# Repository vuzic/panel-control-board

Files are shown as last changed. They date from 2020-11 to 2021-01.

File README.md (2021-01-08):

# Panel Control Hardware

## Power

### Requirements 
* Power button which either boots or sends a signal to the RPI to shutdown.
* Battery status indication (can be crude, maybe just color or flashing to indicate low battery vs charging vs charged)
* Should not draw too much current when off but fully charged
* OE needs to be disabled on panels when PI is off
* MCU with analog voltage from battery
* MCU needs to tell RPI to shut down when battery is <10%

### Ideas
* Use MOSFET rated for 15W (5V/3A) to power on the RPI
* RPI GPIO to act as a power status pin. Shutdown sequence waits for a level change on this pin before cutting the power.
    * High means PI is shutting down; when it goes low, its finished powering off.
# LED Interface

(old README, needs update)

This is a hat designed for a Raspberry Pi Zero. It consists of two headers for I2S microphones (the sort of which are availble for under 2$ on aliexpress) and two level shifted outputs.

The primary purpose is to control 4-wire LED strips using the four pin header. This should also be able to provide the Pi Zero with power.

There's also a HUB-75 connector for driving LED panels. This might be less useful, and probably wasn't neccessary. (These are much better suited to be driven off a PI 3 or 4 if the
frame rate or color depth matters, and some research into [hzeller's](https://github.com/hzeller/rpi-rgb-led-matrix) excellent library points out that the I2S CLK pin is also the same
as the PWM pin which drives the OE signal to the panels for better performance. I'm using a different pin mapping anyway (TODO: write it down..) so it wont work out of the box in any case.)

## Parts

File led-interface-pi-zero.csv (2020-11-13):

Comment | Designator | Footprint | LCSC
1uF | C1,C2,C3,C4 | Capacitor_SMD:C_0603_1608Metric_Pad1.08x0.95mm_HandSolder | C15849
3mm_Mounting_Hole | H1,H2,H3,H4 | project_footprints:NPTH_3mm_ID
PWR | J1 | Connector_PinHeader_2.54mm:PinHeader_2x02_P2.54mm_Vertical
103904-3 | J2 | user_footprints:TE_103904-3
40HAT | J3 | Connector_PinSocket_2.54mm:PinSocket_2x20_P2.54mm_Vertical
HUB-75 | J4 | user_footprints:TE_5-103167-5
ICS-43434 | MK1,MK2 | user_footprints:I2S-MIC_DIP-6
DMG2305UX | Q1 | Package_TO_SOT_SMD:SOT-23 | C150470
DMMT5401 | Q2 | Package_TO_SOT_SMD:SOT-23-6 | C154733
4.7K | R1 | Capacitor_SMD:C_0603_1608Metric_Pad1.08x0.95mm_HandSolder | C23162
100K | R3 | Resistor_SMD:R_0603_1608Metric_Pad0.98x0.95mm_HandSolder | C25803
47K | R5 | Resistor_SMD:R_0603_1608Metric_Pad0.84x1.00mm_HandSolder | C25819
10K | R6 | Resistor_SMD:R_0603_1608Metric_Pad0.84x1.00mm_HandSolder | C25804
TXS0108EPW | U1,U2 | Package_SO:TSSOP-20_4.4x6.5mm_P0.65mm | C17206

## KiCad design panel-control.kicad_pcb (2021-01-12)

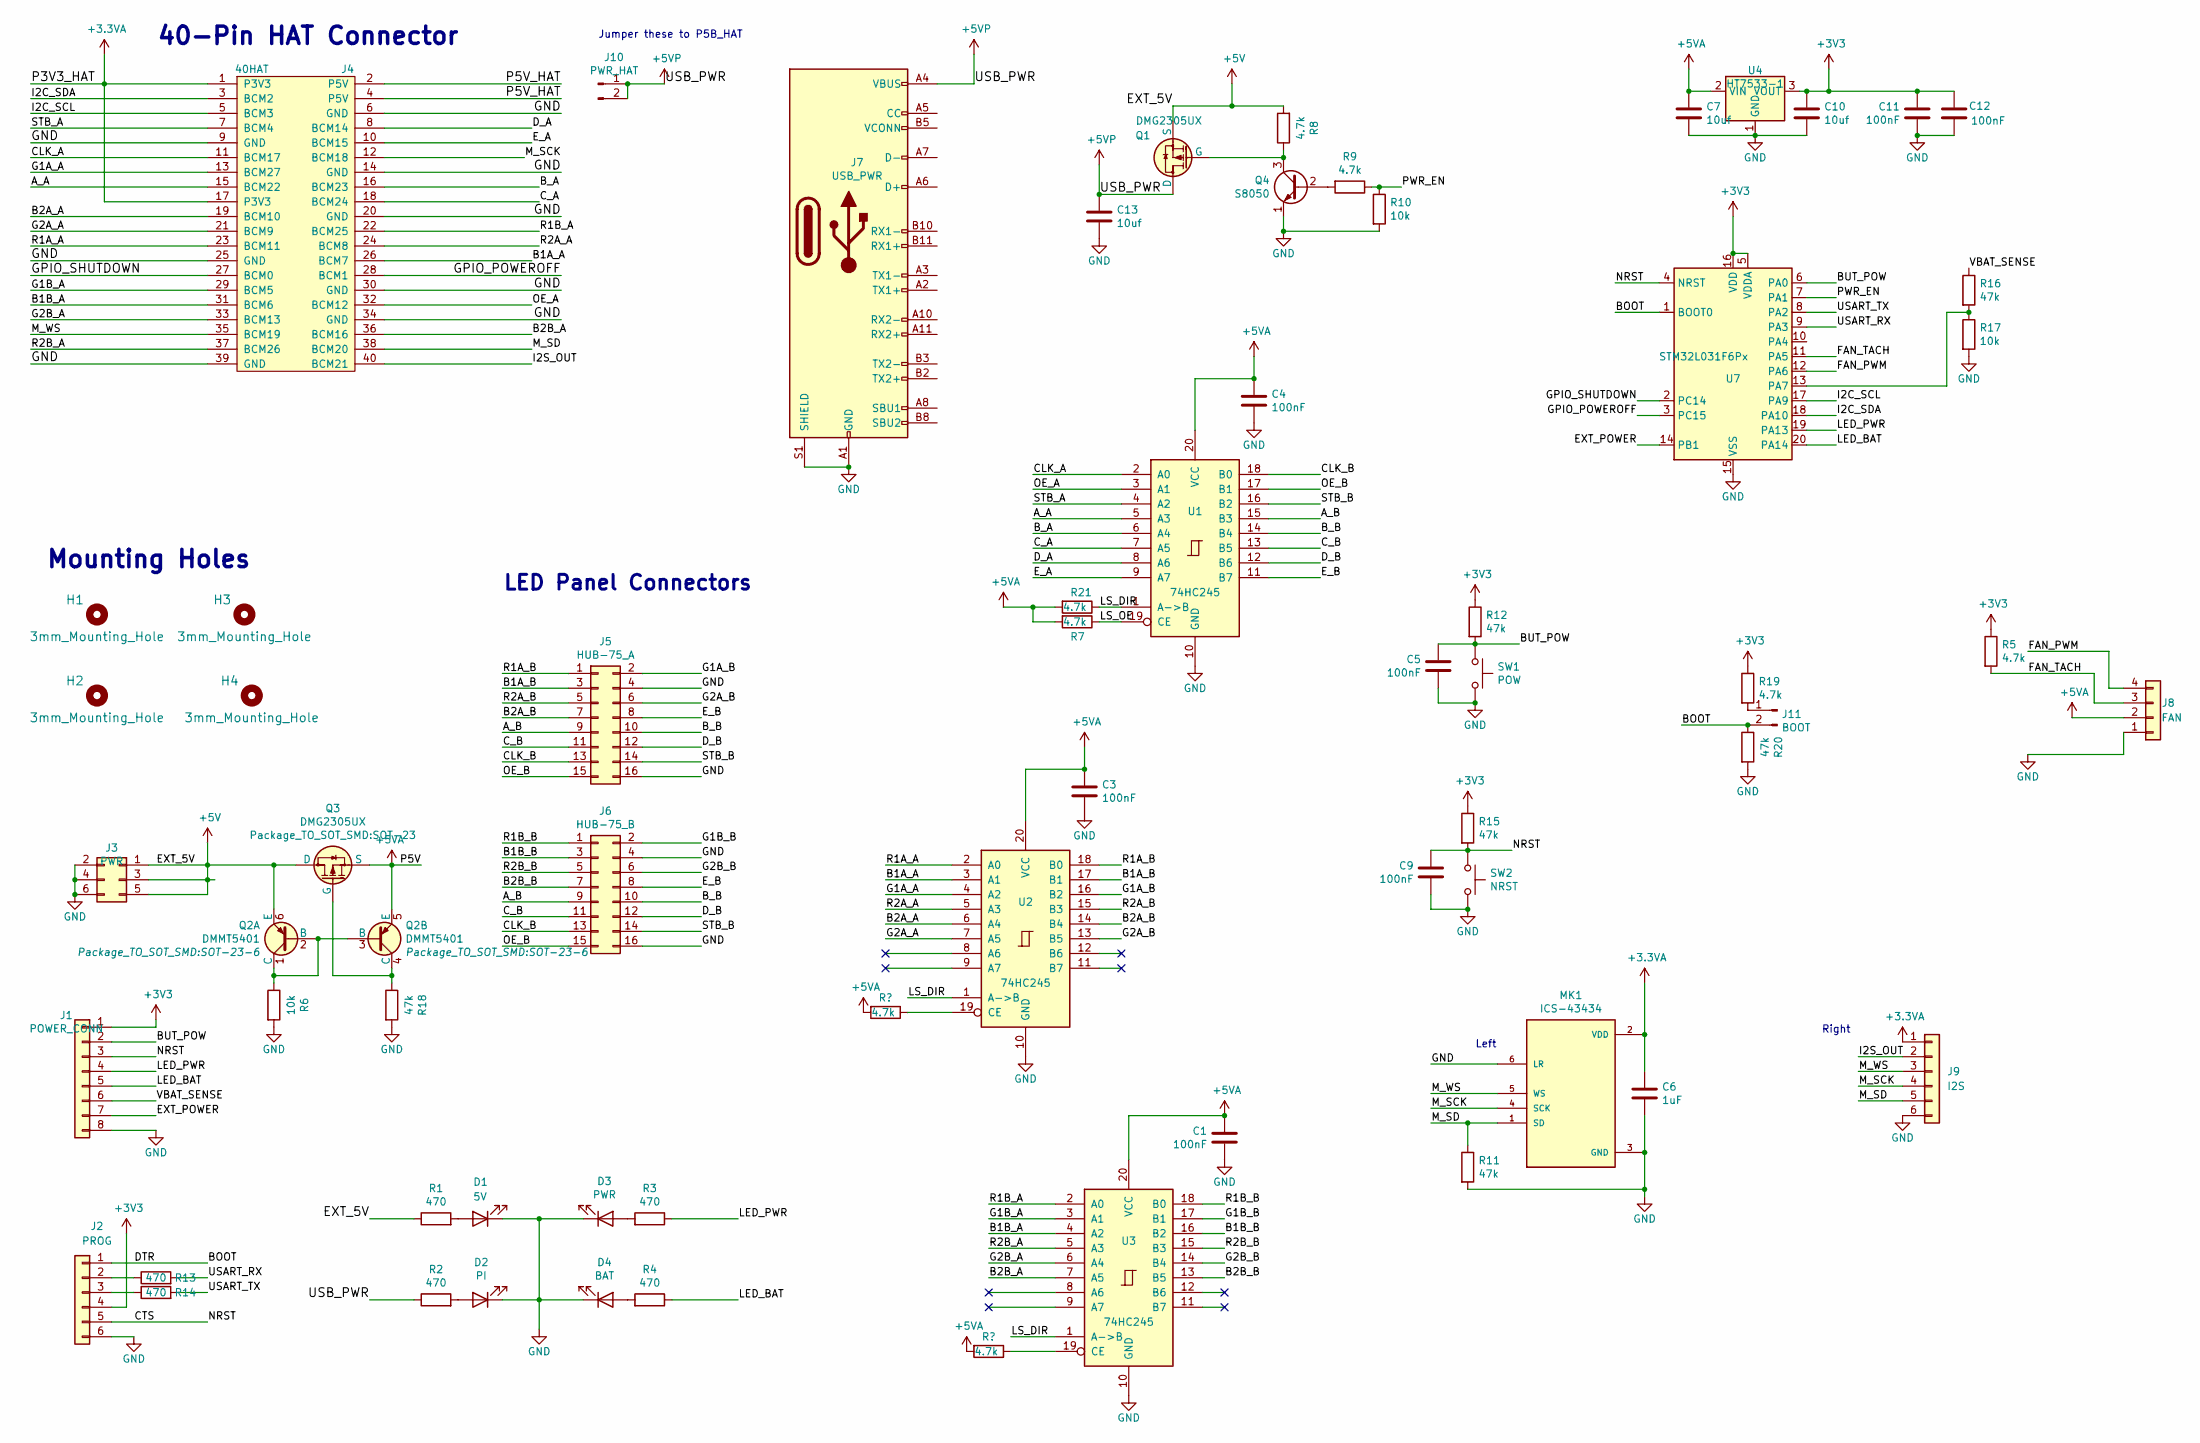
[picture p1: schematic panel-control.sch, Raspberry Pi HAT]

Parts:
C1, C3, C4, C5, C9, C11, C12: 100nF; C_0603_1608Metric; LCSC C14663
C6: 1uF; C_0603_1608Metric; LCSC C15849
C7, C10, C13: 10uf; C_0603_1608Metric; LCSC C19702
D1: 5V; LED_0603_1608Metric; LCSC C72038
D2: PI; LED_0603_1608Metric; LCSC C72038
D3: PWR; LED_0805_2012Metric; LCSC C2293
D4: BAT; LED_0805_2012Metric; LCSC C84256
H1, H2, H3, H4: 3mm_Mounting_Hole; NPTH_3mm_ID
J1: POWER_CONN; Molex_200528-0080_1x08-1MP_P1.00mm_Horizontal
J2: PROG; PinHeader_1x06_P2.54mm_Vertical
J3: PWR; PinHeader_2x03_P2.54mm_Vertical
J4: 40HAT; PinSocket_2x20_P2.54mm_Vertical
J5: HUB-75_A; IDC-Header_2x08_P2.54mm_Vertical
J6: HUB-75_B; IDC-Header_2x08_P2.54mm_Vertical
J7: USB_PWR; USB_C_Receptacle_GCT_USB4085
J8: FAN; FanPinHeader_1x04_P2.54mm_Vertical
J9: I2S; Molex_200528-0060_1x06-1MP_P1.00mm_Horizontal
J10: PWR_HAT; PinHeader_1x02_P2.54mm_Vertical
J11: BOOT; PinHeader_1x02_P2.54mm_Vertical
MK1: ICS-43434; I2S-MIC_DIP-6
Q1, Q3: DMG2305UX; SOT-23; LCSC C144153
Q2: DMMT5401; SOT-23-6; LCSC C154733
Q4: S8050; SOT-23; LCSC C2146
R1, R2, R3, R4, R13, R14: 470; R_0402_1005Metric; LCSC C25117
R5, R7, R8, R9, R19, R21: 4.7k; R_0402_1005Metric; LCSC C25900
R6: 10k; R_0402_1005Metric
R10, R17: 10k; R_0402_1005Metric; LCSC C25744
R11, R16: 47k; R_0402_1005Metric; LCSC C25792
R12, R15: 47k; R_0402_1005Metric; LCSC C25900
R18, R20: 47k; R_0402_1005Metric
SW1: POW; SW_Push_1P1T_NO_6x6mm_H9.5mm
SW2: NRST; SW_Push_1P1T_NO_6x6mm_H9.5mm
U1, U2, U3: 74HC245; SSOP-20_4.4x6.5mm_P0.65mm; LCSC C6779
U4: HT7533-1; SOT-89-3; LCSC C14289
U7: STM32L031F6Px; TSSOP-20_4.4x6.5mm_P0.65mm; LCSC C115208

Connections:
+3.3VA: C6.1, J4.1 (P3V3), J4.17 (P3V3), J9.1, MK1.2 (VDD)
+3V3: C10.1, C11.2, C12.2, J1.1, J2.4, R5.1, R12.1, R15.1, R19.1, U4.3 (VOUT), U7.5 (VDDA), U7.16 (VDD)
+5V: J3.1, J3.3, J3.5, Q1.2 (S), Q2.6 (E), Q3.3 (D), R1.1, R8.2
+5VA: C1.1, C3.1, C4.1, C7.1, J8.2, Q2.5 (E), Q3.2 (S), R7.2, R21.2, U1.20 (VCC), U2.20 (VCC), U3.20 (VCC), U4.2 (VIN); also elsewhere on the board
+5VP: C13.1, J7.A4 (VBUS), J7.A9 (VBUS), J7.B4 (VBUS), J7.B9 (VBUS), J10.1, J10.2, Q1.3 (D), R2.1
/A_A: J4.15 (BCM22), U1.5 (A3)
/A_B: J5.9, J6.9, U1.15 (B3)
/B1A_A: J4.26 (BCM7), U2.3 (A1)
/B1A_B: J5.3, U2.17 (B1)
/B1B_A: J4.31 (BCM6), U3.4 (A2)
/B1B_B: J6.3, U3.16 (B2)
/B2A_A: J4.19 (BCM10), U2.6 (A4)
/B2A_B: J5.7, U2.14 (B4)
/B2B_A: J4.36 (BCM16), U3.7 (A5)
/B2B_B: J6.7, U3.13 (B5)
/BOOT: J2.1, J11.2, R20.1, U7.1 (BOOT0)
/BUT_POW: C5.2, J1.2, R12.2, SW1.1, U7.6 (PA0)
/B_A: J4.16 (BCM23), U1.6 (A4)
/B_B: J5.10, J6.10, U1.14 (B4)
/CLK_A: J4.11 (BCM17), U1.2 (A0)
/CLK_B: J5.13, J6.13, U1.18 (B0)
/CTS: C9.2, J1.3, J2.5, R15.2, SW2.1, U7.4 (NRST)
/C_A: J4.18 (BCM24), U1.7 (A5)
/C_B: J5.11, J6.11, U1.13 (B5)
/D_A: J4.8 (BCM14), U1.8 (A6)
/D_B: J5.12, J6.12, U1.12 (B6)
/EXT_POWER: J1.7, U7.14 (PB1)
/E_A: J4.10 (BCM15), U1.9 (A7)
/E_B: J5.8, J6.8, U1.11 (B7)
/FAN_PWM: J8.4, U7.12 (PA6)
/FAN_TACH: J8.3, R5.2, U7.11 (PA5)
/G1A_A: J4.13 (BCM27), U2.4 (A2)
/G1A_B: J5.2, U2.16 (B2)
/G1B_A: J4.29 (BCM5), U3.3 (A1)
/G1B_B: J6.2, U3.17 (B1)
/G2A_A: J4.21 (BCM9), U2.7 (A5)
/G2A_B: J5.6, U2.13 (B5)
/G2B_A: J4.33 (BCM13), U3.6 (A4)
/G2B_B: J6.6, U3.14 (B4)
/GPIO_POWEROFF: J4.28 (BCM1), U7.3 (PC15)
/GPIO_SHUTDOWN: J4.27 (BCM0), U7.2 (PC14)
/I2C_SCL: J4.5 (BCM3), U7.17 (PA9)
/I2C_SDA: J4.3 (BCM2), U7.18 (PA10)
/I2S_OUT: J4.40 (BCM21), J9.2
/LED_BAT: J1.5, R4.1, U7.20 (PA14)
/LED_PWR: J1.4, R3.1, U7.19 (PA13)
/LS_DIR: R21.1, U1.1 (A->B), U2.1 (A->B), U3.1 (A->B)
/LS_OE: R7.1, U1.19 (CE)
/M_SCK: J4.12 (BCM18), J9.4, MK1.4 (SCK)
/M_SD: J4.38 (BCM20), J9.5, MK1.1 (SD), R11.1
/M_WS: J4.35 (BCM19), J9.3, MK1.5 (WS)
/OE_A: J4.32 (BCM12), U1.3 (A1)
/OE_B: J5.15, J6.15, U1.17 (B1)
/P5V_HAT: J4.2 (P5V), J4.4 (P5V)
/PWR_EN: R9.1, R10.1, U7.7 (PA1)
/R1A_A: J4.23 (BCM11), U2.2 (A0)
/R1A_B: J5.1, U2.18 (B0)
/R1B_A: J4.22 (BCM25), U3.2 (A0)
/R1B_B: J6.1, U3.18 (B0)
/R2A_A: J4.24 (BCM8), U2.5 (A3)
/R2A_B: J5.5, U2.15 (B3)
/R2B_A: J4.37 (BCM26), U3.5 (A3)
/R2B_B: J6.5, U3.15 (B3)
/STB_A: J4.7 (BCM4), U1.4 (A2)
/STB_B: J5.14, J6.14, U1.16 (B2)
/USART_RX: R13.2, U7.9 (PA3)
/USART_TX: R14.2, U7.8 (PA2)
/VBAT_SENSE: J1.6, R16.1
GND: C1.2, C3.2, C4.2, C5.1, C6.2, C7.2, C9.1, C10.2, C11.1, C12.1, C13.2, D1.1 (K), D2.1 (K), D3.1 (K), D4.1 (K), J1.8, J2.6, J3.2, J3.4, J3.6, J4.6 (GND), J4.9 (GND), J4.14 (GND), J4.20 (GND), J4.25 (GND), J4.30 (GND), J4.34 (GND), J4.39 (GND), J5.4, J5.16, J6.4, J6.16, J7.A1 (GND), J7.A12 (GND), J7.B1 (GND), J7.B12 (GND), J7.S1 (SHIELD), J8.1, J9.6, MK1.3 (GND), MK1.6 (LR), Q4.1 (E), R6.2, R10.2, R11.2, R17.2, R18.2, R20.2, SW1.2, SW2.2, U1.10 (GND), U2.10 (GND), U3.10 (GND), U4.1 (GND), U7.15 (VSS)
unnamed: D1.2 (A), R1.2
unnamed: D2.2 (A), R2.2
unnamed: D3.2 (A), R3.2
unnamed: D4.2 (A), R4.2
unnamed: J2.2, R13.1
unnamed: J2.3, R14.1
unnamed: J11.1, R19.2
unnamed: Q1.1 (G), Q4.3 (C), R8.1
unnamed: Q2.1 (C), Q2.2 (B), Q2.3 (B), R6.1
unnamed: Q2.4 (C), Q3.1 (G), R18.1
unnamed: Q4.2 (B), R9.2
unnamed: R16.2, R17.1, U7.13 (PA7)
unnamed 87: U2.19 (CE); also elsewhere on the board
unnamed 88: U3.19 (CE); also elsewhere on the board

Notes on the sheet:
Mounting Holes
40-Pin HAT Connector
LED Panel Connectors
Left
Right
Jumper these to P5B_HAT

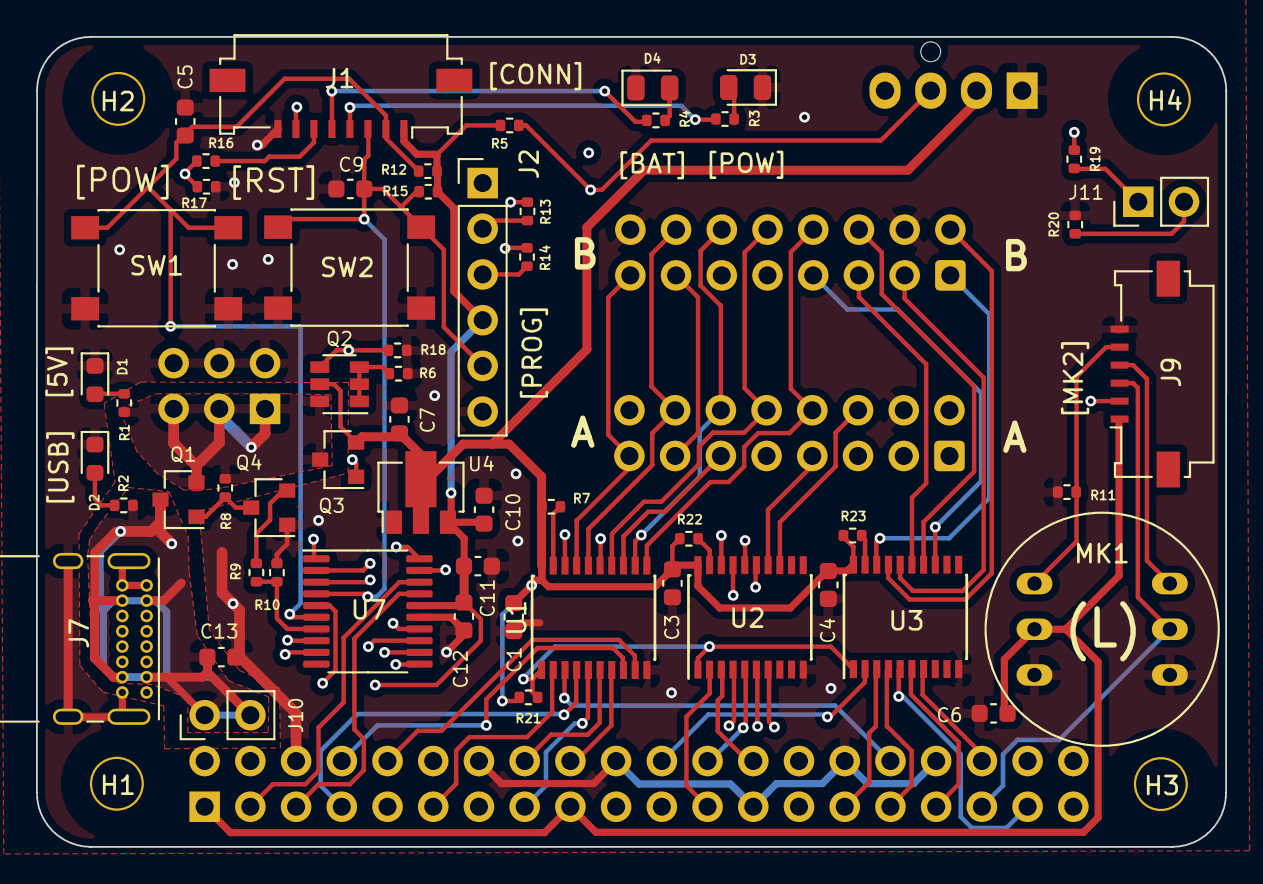
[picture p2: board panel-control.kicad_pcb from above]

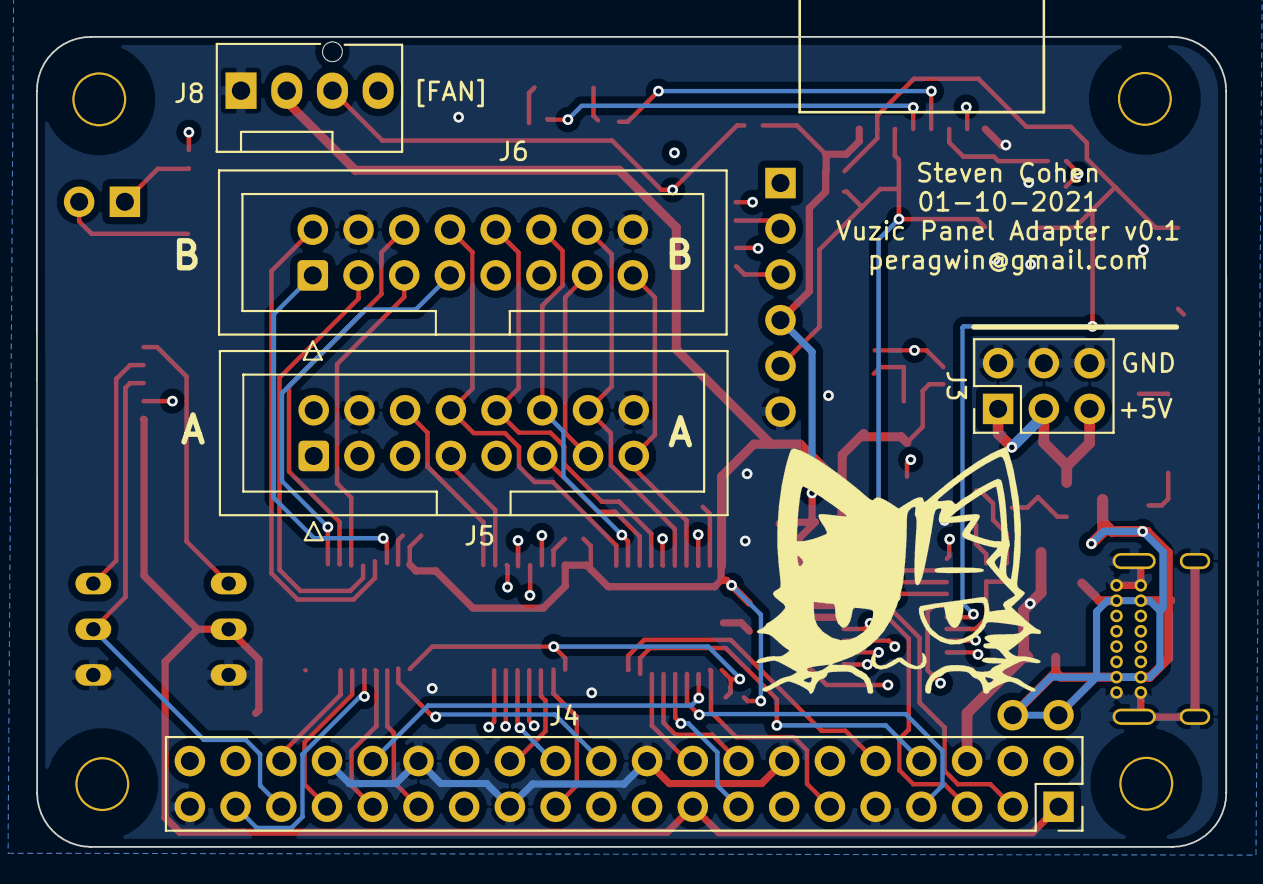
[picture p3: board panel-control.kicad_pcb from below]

Board: 4 copper layers, 66.1 x 45.0 mm, 65 parts (5 on the bottom side), 83 nets.

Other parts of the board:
R22, R23: 4.7k; R_0402_1005Metric

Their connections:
+5VA: R22.2, R23.2; also elsewhere on the board
unnamed 87: R22.1; also elsewhere on the board
unnamed 88: R23.1; also elsewhere on the board

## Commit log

2021-01-07 work on schematic for panel controller
    [led-interface-pi-zero.sch, panel-control.kicad_pcb, panel-control.sch]
2021-01-07 fix labels and tweak pwr_en
    [panel-control.sch]
2021-01-07 mainly finished schematic revision
    [panel-control.sch]
2021-01-07 update pcb from new sch
    [panel-control.kicad_pcb, panel-control.sch]
2021-01-07 add fan connector to sch
    [panel-control.kicad_pcb, panel-control.sch]
2021-01-08 fix footprints
    [panel-control.kicad_pcb, panel-control.sch]
2021-01-08 work on new pcb layout
    [panel-control.kicad_pcb, panel-control.sch]
2021-01-08 start laying traces
    [panel-control.kicad_pcb, panel-control.sch]
2021-01-08 sort of finished layout
    [panel-control.kicad_pcb, panel-control.sch]
2021-01-08 nearly ready to submit
    [panel-control.kicad_pcb, panel-control.sch]
2021-01-10 tweaks to components
    [panel-control.kicad_pcb, panel-control.sch]
2021-01-10 maybe finished revision with micro usb output
    [panel-control.kicad_pcb, panel-control.sch]
2021-01-11 better reverse current protection and usb-c power
    [panel-control.kicad_pcb, panel-control.sch]
2021-01-11 more revisions, maybe ready to submit
    [panel-control.kicad_pcb, panel-control.sch]
2021-01-12 finally submitted
    [panel-control.kicad_pcb, panel-control.sch]
2021-01-13 annotate sch
    [panel-control.sch]
